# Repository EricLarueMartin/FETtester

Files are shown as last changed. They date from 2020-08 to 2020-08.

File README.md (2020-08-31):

# FETtester
Board to attach to an Arduino to characterize transistors.

Allows adjusting drain (collector) and gate (base) voltage and reading:
gate-source (base-emitter) voltage, 
drain-source (collector-emitter) voltage,
gate (base) current,
drain (collector) current,
and temperature.

Values are level shifted by op amp circuits and measured on the Arduino ADCs.

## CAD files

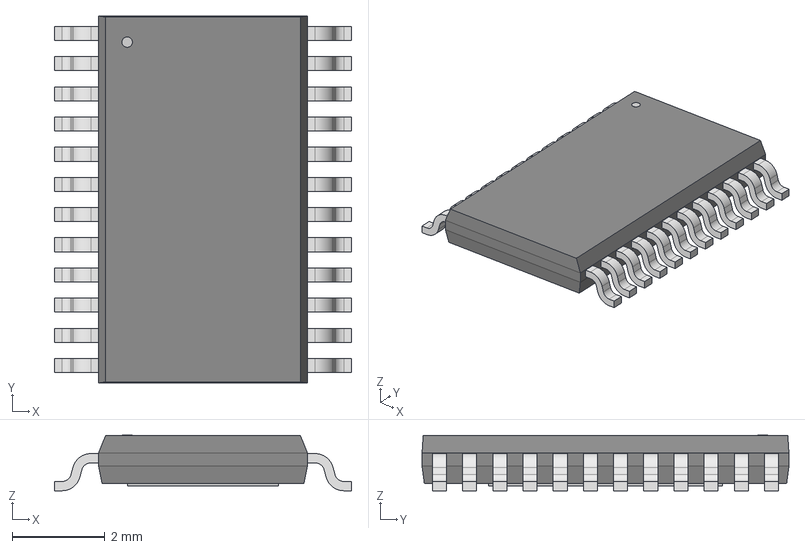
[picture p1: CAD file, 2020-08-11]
RE_24_ADI-L.step
6.40 x 7.90 x 1.20 mm

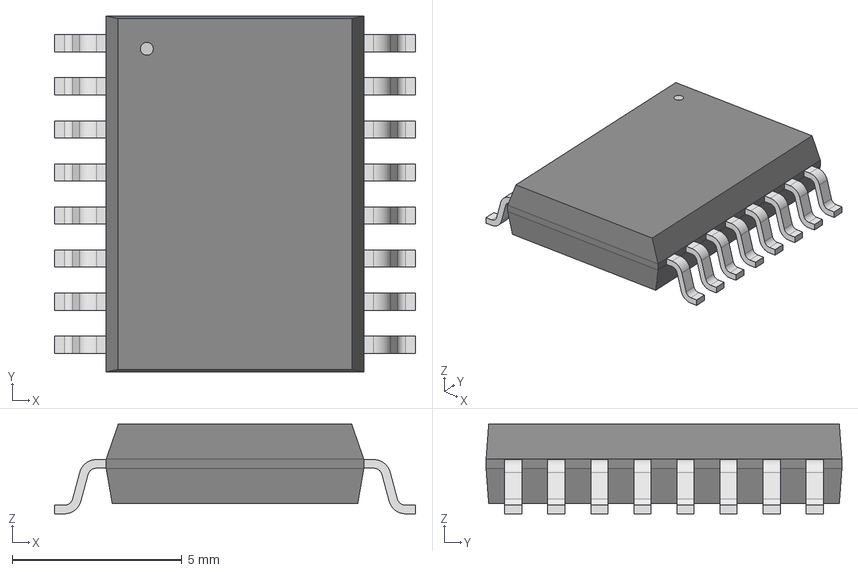
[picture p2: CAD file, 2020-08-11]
RW_16_ADI-M.step
10.6 x 10.5 x 2.64 mm

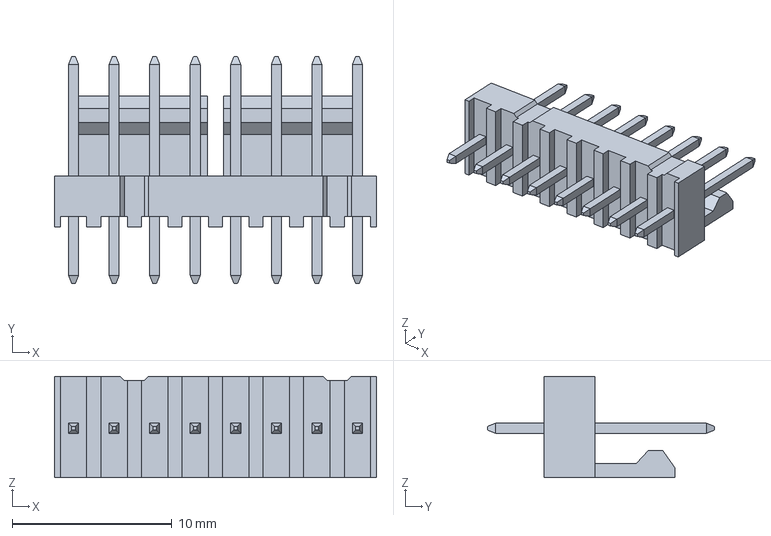
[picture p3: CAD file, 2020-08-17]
22112082.stp
20.2 x 14.2 x 6.35 mm

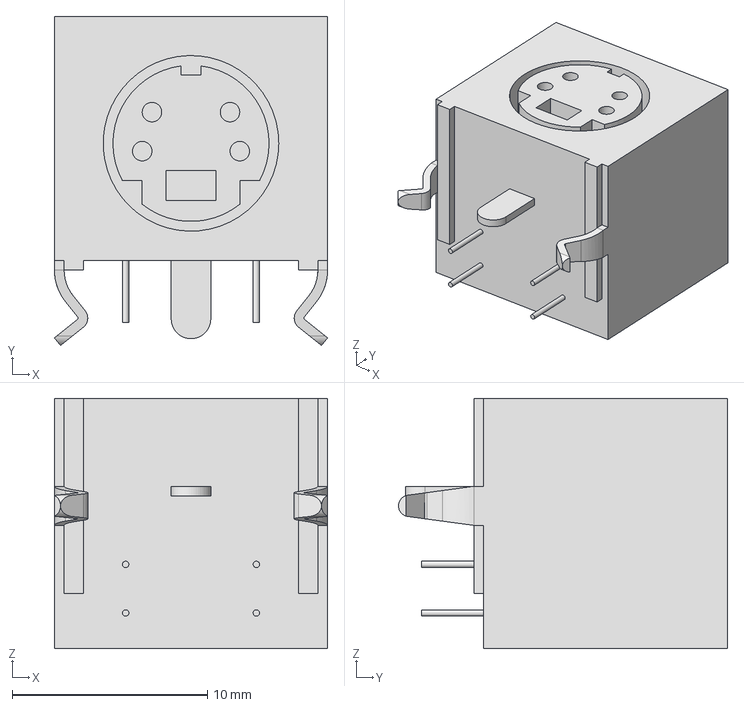
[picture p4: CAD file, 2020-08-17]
5749230.stp
14.0 x 16.9 x 12.8 mm

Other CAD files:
RE_24_ADI.step
RE_24_ADI-M.step
RW_16_ADI-L.step
RW_16_ADI.step

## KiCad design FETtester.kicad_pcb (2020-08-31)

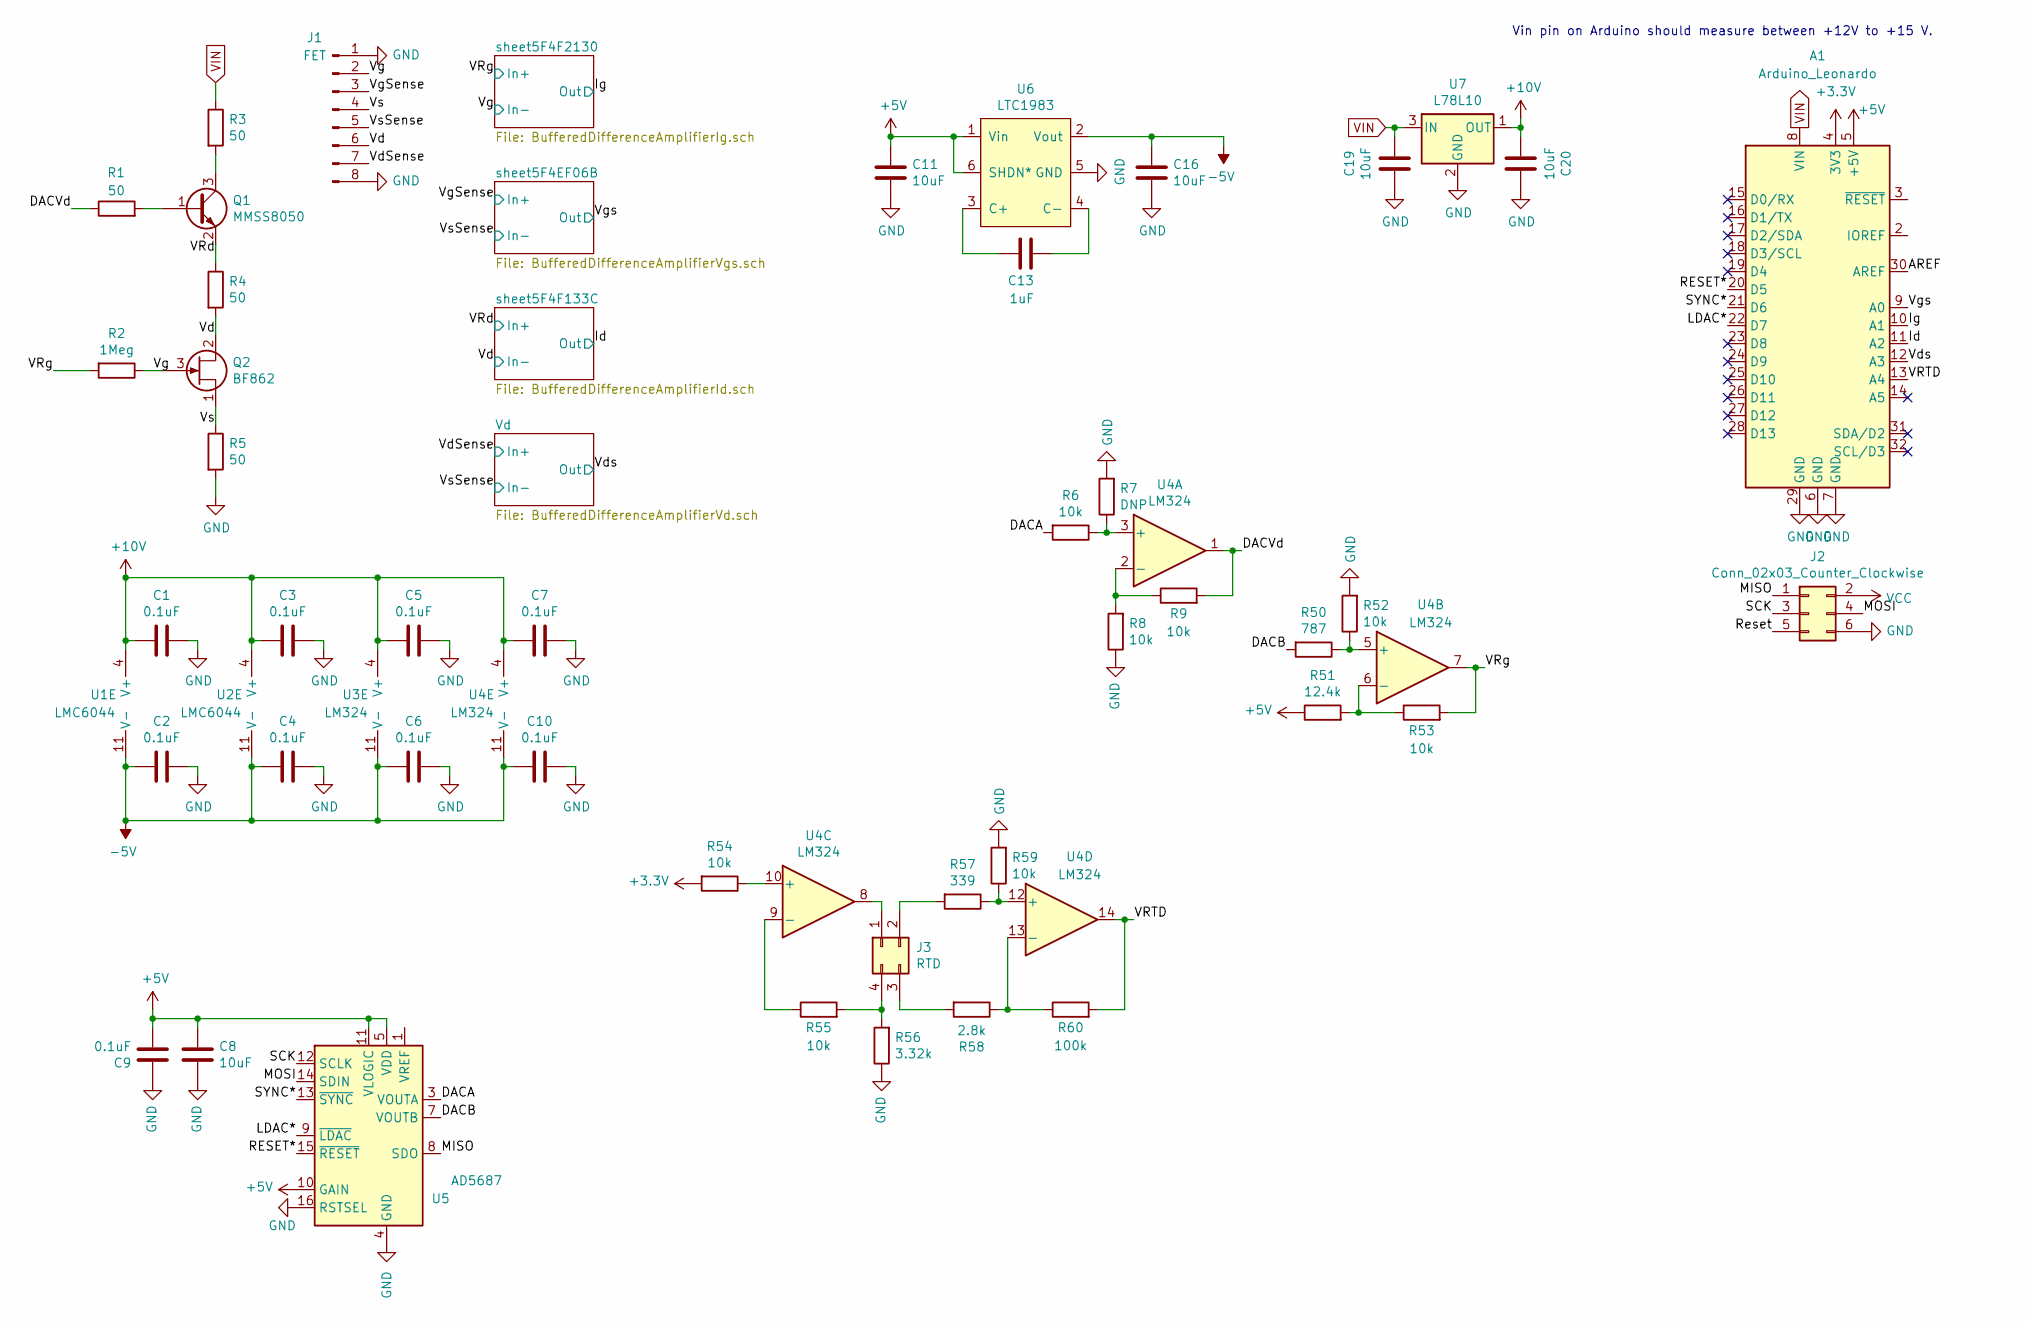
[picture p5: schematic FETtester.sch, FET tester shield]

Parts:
A1: Arduino_Leonardo; Arduino_UNO_R3_WithMountingHoles
C1, C2, C3, C4, C5, C6, C7, C9, C10: 0.1uF; C_0603_1608Metric
C8, C11, C16, C19, C20: 10uF; C_0603_1608Metric
C13: 1uF; C_0603_1608Metric
J1: FET; PinHeader_1x08_P2.54mm_Vertical
J2: Conn_02x03_Counter_Clockwise; PinSocket_2x03_P2.54mm_Vertical
J3: RTD; DIN_4
Q1: MMSS8050; SOT-23
Q2: BF862; SOT-23
R1, R3, R4, R5: 50; R_0603_1608Metric
R2: 1Meg; R_0603_1608Metric
R6, R8, R9, R52, R53, R54, R55, R59: 10k; R_0603_1608Metric
R7: DNP; R_0603_1608Metric
R50: 787; R_0603_1608Metric
R51: 12.4k; R_0603_1608Metric
R56: 3.32k; R_0603_1608Metric
R57: 339; R_0603_1608Metric
R58: 2.8k; R_0603_1608Metric
R60: 100k; R_0603_1608Metric
U1, U2: LMC6044; SOIC-14_3.9x8.7mm_P1.27mm
U3, U4: LM324; SOIC-14_3.9x8.7mm_P1.27mm
U5: AD5687; TSSOP-16_4.4x5mm_P0.65mm
U6: LTC1983; TSOT-23-6
U7: L78L10; SOT-89-3

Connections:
+3V3: A1.4 (3V3), R54.2
+5V: A1.5 (+5V), C8.1, C9.2, C11.1, R51.1, U5.5 (VDD), U5.10 (GAIN), U5.11 (VLOGIC), U6.1 (Vin), U6.6 (SHDN*); also elsewhere on the board
+10V: C1.2, C3.2, C5.2, C7.2, C20.2, U1.4 (V+), U2.4 (V+), U3.4 (V+), U4.4 (V+), U7.1 (OUT)
-5V: C2.2, C4.2, C6.2, C10.2, C16.1, U1.11 (V-), U2.11 (V-), U3.11 (V-), U4.11 (V-), U6.2 (Vout)
/AREF: A1.30 (AREF)
/DACA: R6.2, U5.3 (VOUTA)
/DACB: R50.2, U5.7 (VOUTB)
/DACVd: R1.1, R9.2, U4.1
/Id: A1.11 (A2); also elsewhere on the board
/Ig: A1.10 (A1); also elsewhere on the board
/LDAC*: A1.22 (D7), U5.9 (~LDAC)
/MISO: J2.1, U5.8 (SDO)
/MOSI: J2.4, U5.14 (SDIN)
/RESET*: A1.20 (D5), U5.15 (~RESET)
/Reset: J2.5
/SCK: J2.3, U5.12 (SCLK)
/SYNC*: A1.21 (D6), U5.13 (~SYNC)
/VRTD: A1.13 (A4), R60.2, U4.14
/VRd: Q1.2 (E), R4.1; also elsewhere on the board
/VRg: R2.2, R53.2, U4.7; also elsewhere on the board
/Vd: J1.6, Q2.2 (D), R4.2; also elsewhere on the board
/VdSense: J1.7; also elsewhere on the board
/Vds: A1.12 (A3); also elsewhere on the board
/Vg: J1.2, Q2.3 (G), R2.1; also elsewhere on the board
/VgSense: J1.3; also elsewhere on the board
/Vgs: A1.9 (A0); also elsewhere on the board
/Vs: J1.4, Q2.1 (S), R5.1
/VsSense: J1.5; also elsewhere on the board
GND: A1.6 (GND), A1.7 (GND), A1.29 (GND), C1.1, C2.1, C3.1, C4.1, C5.1, C6.1, C7.1, C8.2, C9.1, C10.1, C11.2, C16.2, C19.2, C20.1, J1.1, J1.8, J2.6, R5.2, R7.2, R8.1, R52.2, R56.1, R59.2, U5.4 (GND), U5.16 (RSTSEL), U6.5 (GND), U7.2 (GND); also elsewhere on the board
unnamed: C13.1, U6.3 (C+)
unnamed: C13.2, U6.4 (C-)
unnamed: J3.1, U4.8
unnamed: J3.2, R57.2
unnamed: J3.3, R58.2
unnamed: J3.4, R55.2, R56.2
unnamed: Q1.1 (B), R1.2
unnamed: Q1.3 (C), R3.2
unnamed: R6.1, R7.1, U4.3 (+)
unnamed: R8.2, R9.1, U4.2 (-)
unnamed: R50.1, R52.1, U4.5 (+)
unnamed: R51.2, R53.1, U4.6 (-)
unnamed: R54.1, U4.10 (+)
unnamed: R55.1, U4.9 (-)
unnamed: R57.1, R59.1, U4.12 (+)
unnamed: R58.1, R60.1, U4.13 (-)
VCC: J2.2
VIN: A1.8 (VIN), C19.1, R3.1, U7.3 (IN)

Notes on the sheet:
Vin pin on Arduino should measure between +12V to +15 V.

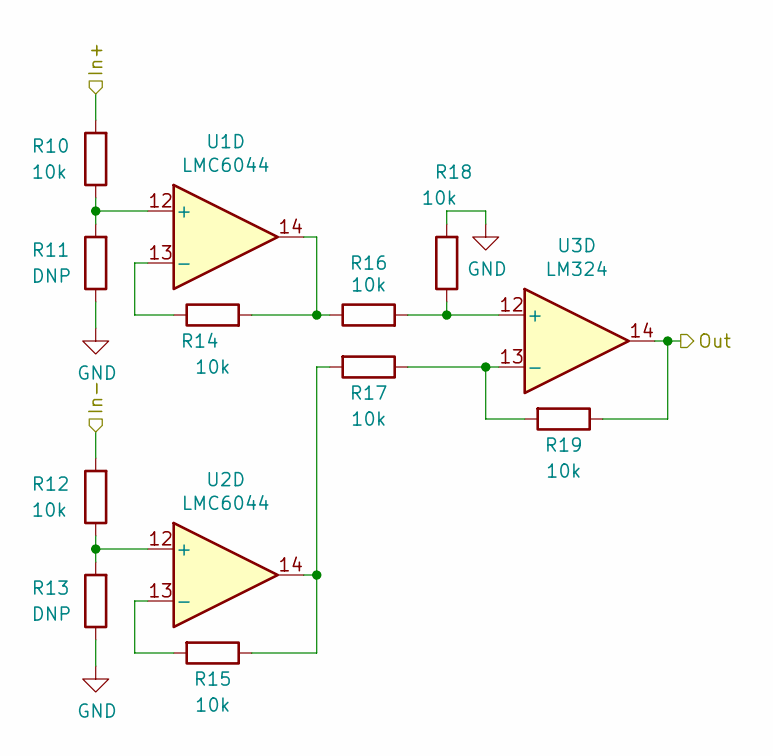
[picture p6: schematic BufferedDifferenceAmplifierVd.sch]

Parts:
R10, R12, R14, R15, R16, R17, R18, R19: 10k; R_0603_1608Metric
R11, R13: DNP; R_0603_1608Metric
U1, U2: LMC6044; SOIC-14_3.9x8.7mm_P1.27mm
U3: LM324; SOIC-14_3.9x8.7mm_P1.27mm

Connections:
/VdSense: R10.2; also elsewhere on the board
/Vds: R19.1, U3.14; also elsewhere on the board
/VsSense: R12.2; also elsewhere on the board
GND: R11.1, R13.1, R18.2; also elsewhere on the board
unnamed: R10.1, R11.2, U1.12 (+)
unnamed: R12.1, R13.2, U2.12 (+)
unnamed: R14.1, U1.13 (-)
unnamed: R14.2, R16.1, U1.14
unnamed: R15.1, R17.2, U2.14
unnamed: R15.2, U2.13 (-)
unnamed: R16.2, R18.1, U3.12 (+)
unnamed: R17.1, R19.2, U3.13 (-)

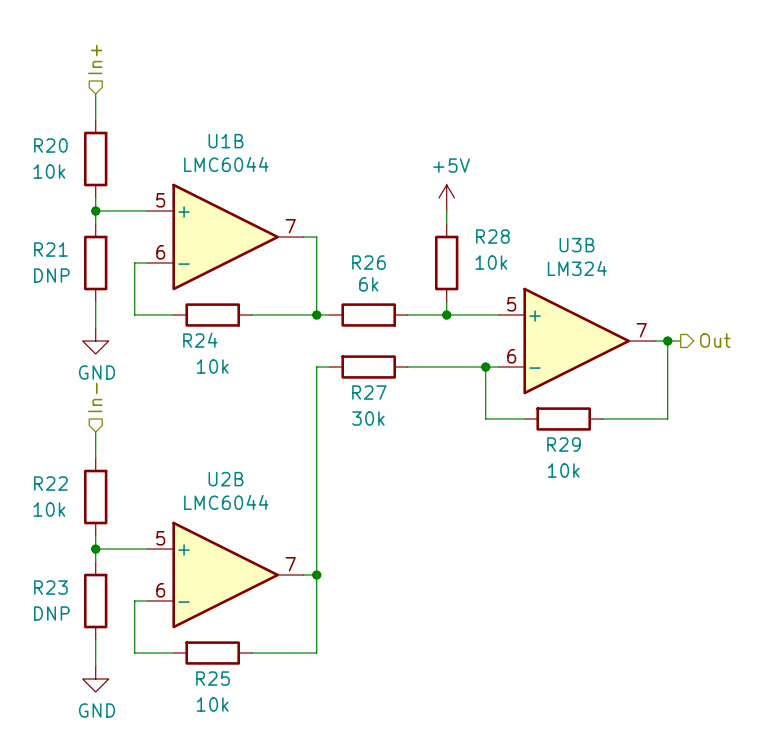
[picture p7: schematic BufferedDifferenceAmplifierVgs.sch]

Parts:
R20, R22, R24, R25, R28, R29: 10k; R_0603_1608Metric
R21, R23: DNP; R_0603_1608Metric
R26: 6k; R_0603_1608Metric
R27: 30k; R_0603_1608Metric
U1, U2: LMC6044; SOIC-14_3.9x8.7mm_P1.27mm
U3: LM324; SOIC-14_3.9x8.7mm_P1.27mm

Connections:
+5V: R28.2; also elsewhere on the board
/VgSense: R20.2; also elsewhere on the board
/Vgs: R29.1, U3.7; also elsewhere on the board
/VsSense: R22.2; also elsewhere on the board
GND: R21.1, R23.1; also elsewhere on the board
unnamed: R20.1, R21.2, U1.5 (+)
unnamed: R22.1, R23.2, U2.5 (+)
unnamed: R24.1, U1.6 (-)
unnamed: R24.2, R26.1, U1.7
unnamed: R25.1, R27.2, U2.7
unnamed: R25.2, U2.6 (-)
unnamed: R26.2, R28.1, U3.5 (+)
unnamed: R27.1, R29.2, U3.6 (-)

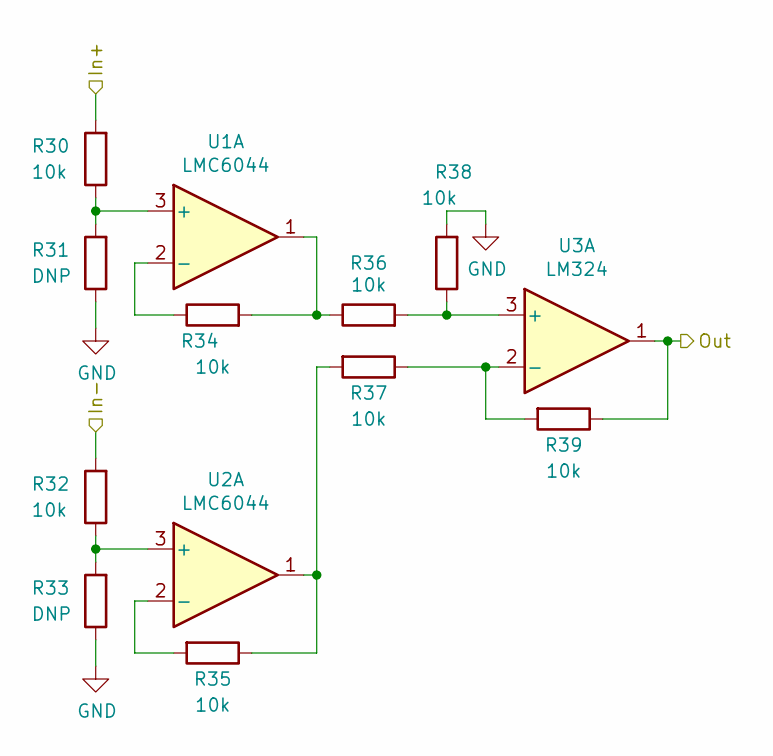
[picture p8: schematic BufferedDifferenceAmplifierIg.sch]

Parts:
R30, R32, R34, R35, R36, R37, R38, R39: 10k; R_0603_1608Metric
R31, R33: DNP; R_0603_1608Metric
U1, U2: LMC6044; SOIC-14_3.9x8.7mm_P1.27mm
U3: LM324; SOIC-14_3.9x8.7mm_P1.27mm

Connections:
/Ig: R39.1, U3.1; also elsewhere on the board
/VRg: R30.2; also elsewhere on the board
/Vg: R32.2; also elsewhere on the board
GND: R31.1, R33.1, R38.2; also elsewhere on the board
unnamed: R30.1, R31.2, U1.3 (+)
unnamed: R32.1, R33.2, U2.3 (+)
unnamed: R34.1, U1.2 (-)
unnamed: R34.2, R36.1, U1.1
unnamed: R35.1, R37.2, U2.1
unnamed: R35.2, U2.2 (-)
unnamed: R36.2, R38.1, U3.3 (+)
unnamed: R37.1, R39.2, U3.2 (-)

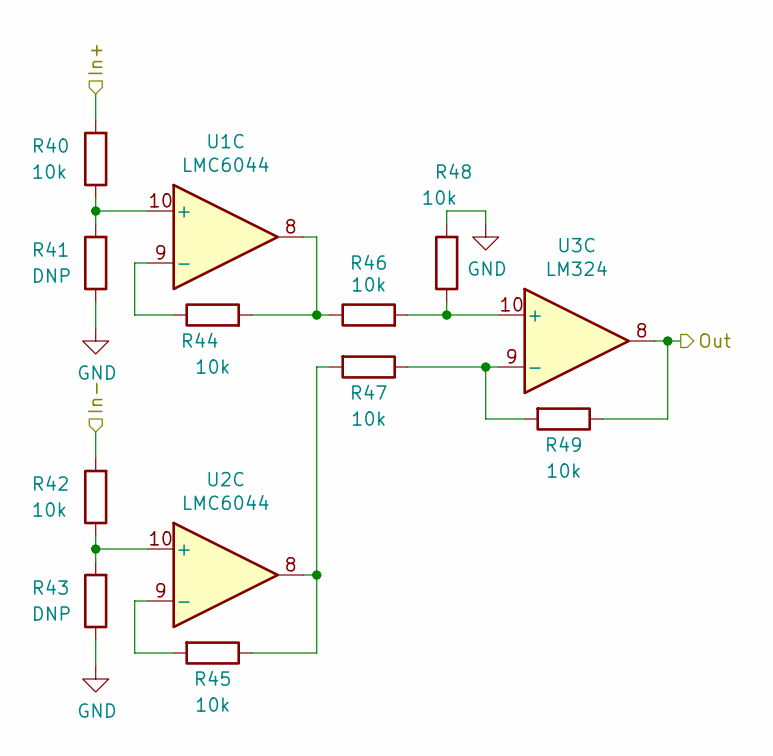
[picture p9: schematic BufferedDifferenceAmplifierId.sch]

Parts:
R40, R42, R44, R45, R46, R47, R48, R49: 10k; R_0603_1608Metric
R41, R43: DNP; R_0603_1608Metric
U1, U2: LMC6044; SOIC-14_3.9x8.7mm_P1.27mm
U3: LM324; SOIC-14_3.9x8.7mm_P1.27mm

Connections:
/Id: R49.1, U3.8; also elsewhere on the board
/VRd: R40.2; also elsewhere on the board
/Vd: R42.2; also elsewhere on the board
GND: R41.1, R43.1, R48.2; also elsewhere on the board
unnamed: R40.1, R41.2, U1.10 (+)
unnamed: R42.1, R43.2, U2.10 (+)
unnamed: R44.1, U1.9 (-)
unnamed: R44.2, R46.1, U1.8
unnamed: R45.1, R47.2, U2.8
unnamed: R45.2, U2.9 (-)
unnamed: R46.2, R48.1, U3.10 (+)
unnamed: R47.1, R49.2, U3.9 (-)

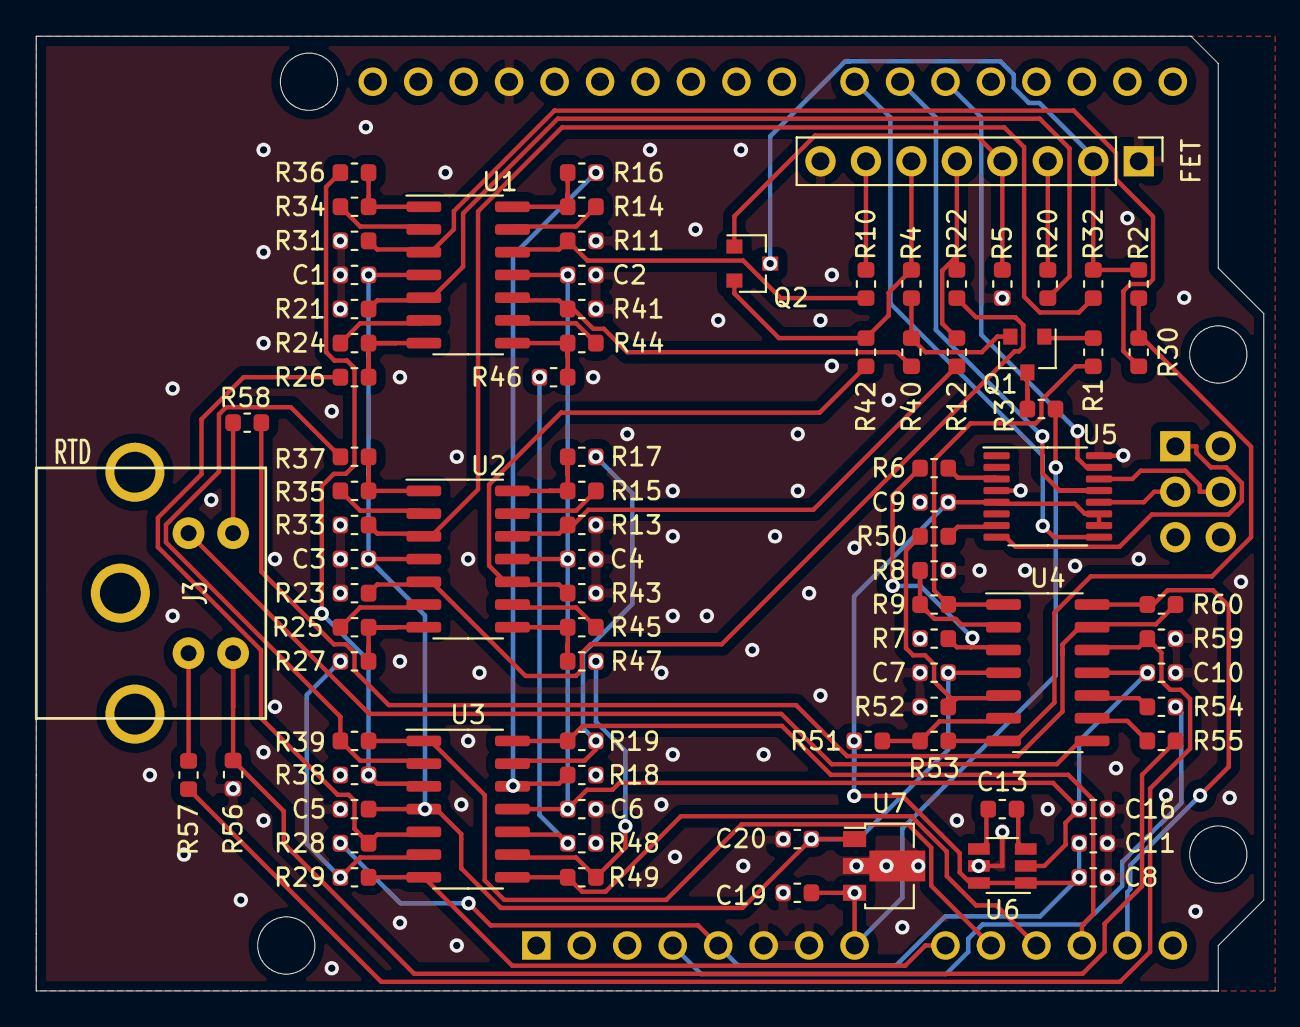
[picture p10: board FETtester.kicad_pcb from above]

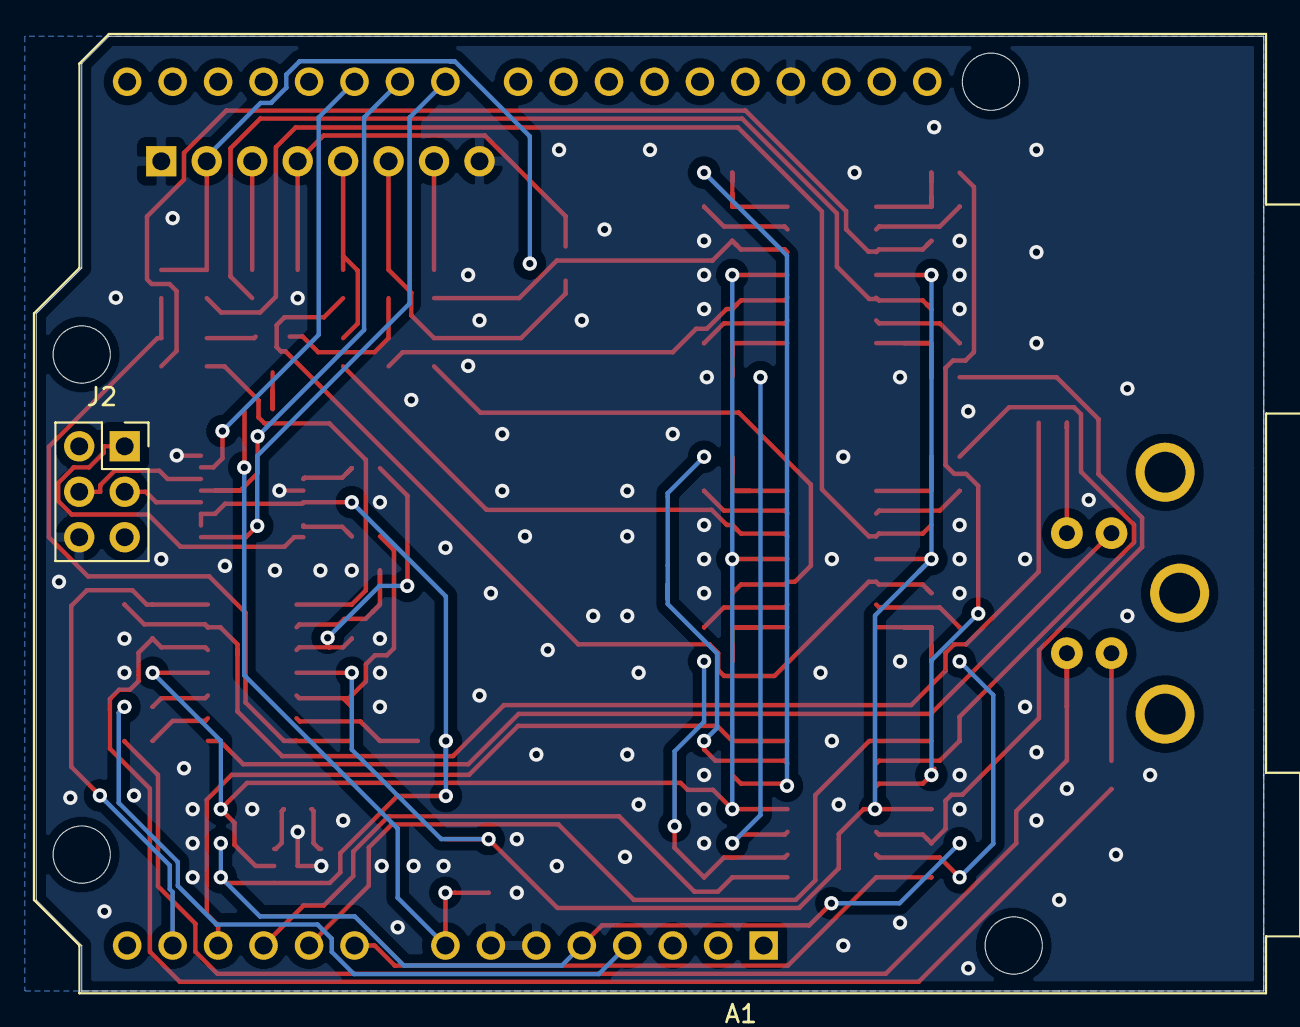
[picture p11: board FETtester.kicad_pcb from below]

Board: 2 copper layers, 68.6 x 53.3 mm, 88 parts (2 on the bottom side), 76 nets.

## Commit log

2020-08-11 Minor routing changes.
    [FETtester.kicad_pcb]
2020-08-17 Added negative swing on gate-source bias and RTD connection.
    [22112082.stp, 5749230.stp, BufferedDifferenceAmplifierId.sch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]
2020-08-31 Fixed missing connection for RTD line.
    [FETtester-B_Cu.gbr, FETtester-B_Mask.gbr, FETtester-Edge_Cuts.gbr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]
